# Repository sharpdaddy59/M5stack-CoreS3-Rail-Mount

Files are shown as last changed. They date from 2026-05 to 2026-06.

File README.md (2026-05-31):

# hydro-cores3-mount

Parametric OpenSCAD pipe-clamp + TS35 DIN-rail section for the
M5Stack CoreS3 on a vertical 1-1/2" Schedule-40 PVC pipe. Sibling
to [`hydro-tapco-mount`](../hydro-tapco-mount) — same pipe, same
clamp pattern, designed to share the rig with the camera mount.

The CoreS3 has a female TS35 clip on its back (35 mm × 7.5 mm
per IEC 60715). This part presents a printed male TS35 rail
section that the device clips onto. The rail runs **horizontally**
— perpendicular to the pipe, the standard DIN-rail orientation —
so gravity seats the device's spring-clip on the lower flange.
Slide the device on from either end of the rail. Reposition height
by loosening the clamp bolts and sliding the whole assembly up or
down the pipe.

The plain clamp half can optionally carry a **Seeed Grove DHT20**
temperature/humidity sensor on an extended bolt ear — see
[DHT20 sensor mount](#dht20-sensor-mount-optional) below.

## Files

| File | Re-render with | Notes |
|---|---|---|
| [`cores3-mount.scad`](cores3-mount.scad) | — | Source. Set `mode` at the top. |
| `cores3-mount_rail.stl` | `mode = "half_a"` (the rail half) | Print **one** |
| `cores3-mount_clamp.stl` | `mode = "half_b"` (the plain half) | Print **one** |
| `cores3-mount_clamp_DHT20.stl` | `mode = "half_b"` + `SENSOR_ENABLE = true` | Clamp half with the [DHT20 pad](#dht20-sensor-mount-optional). Print this **instead of** the plain clamp half. |

## BOM (per mount)

- 2 × M4 socket-cap bolts, 16 mm long (clamp bolts — one per side)
- 2 × M4 hex nuts (captive, one in each of Half A's bolt ears,
  hidden behind the rail once installed)
- A piece of 1-1/2" Schedule-40 PVC pipe (nominal OD 48.26 mm)
- An M5Stack CoreS3

**Optional — DHT20 sensor mount** (when `SENSOR_ENABLE = true`):

- 1 × Seeed Grove DHT20 temperature/humidity board
- 3 × M2 screws (length ≈ board thickness + pad thickness + nut)
- 3 × M2 hex nuts (captive in the pad's back-face pockets)

## Render

| Mode | Renders |
|---|---|
| `"half_a"` | Rail half — print one; rail-flange side down, supports around the screw-hole area. |
| `"half_b"` | Plain half — print one. |
| `"assembly"` | Both halves on a transparent dummy pipe. |
| `"exploded"` | Both halves separated with dummy bolts and nuts. |

Render (F6), export STL.

## Print orientation

**Half A (rail half):** prints **rail-flange side down** — the
flat rail face on the bed. The flange overhangs land directly on
the build plate, so they need no support, but the bolt-ear /
screw-hole area now overhangs the bed: **add supports around the
screw holes.**

**Half B (plain half):** prints with the bore axis vertical — it
stands as a half-tube on the bed, body and ears extruding as a
constant cross-section per layer, **no supports needed.**

## Print settings

- **Material:** PETG. Better fatigue tolerance for the
  captive-nut clamp force, and humidity-tolerant.
- **Layer height:** 0.2 mm.
- **Infill:** 20 % gyroid or grid.
- **Perimeters:** 3.
- **Supports:** around Half A's screw-hole area only; none for
  Half B.

## DHT20 sensor mount (optional)

Half B (the plain clamp half) can carry a **Seeed Grove DHT20**
temp/humidity board on a flat pad that extends one bolt ear. Turn
it on with `SENSOR_ENABLE = true` near the top of the SCAD; with it
`false` the clamp renders exactly as stock.

How it's laid out:

- The board bolts **flat** against the ear's outer (back) face and
  is mounted **vertically** — its long axis runs along the pipe so
  it stands up alongside the clamp rather than cantilevering far
  radially.
- Three **M2** through-holes match the Grove footprint: a pair on
  the connector edge `SENSOR_PAIR_DX` apart (20 mm), plus a single
  hole `SENSOR_PAIR_TO_SINGLE` away (30 mm). M2 nuts drop into
  **captive hex pockets on the pad's inner face**, so you only turn
  the screw.
- The holes sit **outboard of the ear tip** (`SENSOR_HOLE_INSET_X`)
  so the board clears the M4 clamp bolt — the bolt-head counterbore
  stays open through the pad, leaving hex-key access beside the
  board. **Tighten the clamp bolts before fitting the sensor.**
- The pad sits **flush with one clamp end** and the board overhangs
  the other; that flush edge is what keeps Half B printing
  **support-free**. Print with the flush end on the bed
  (`SENSOR_EXTEND_DIR = -1`, the default, needs no re-orientation;
  `+1` flips which end overhangs and wants a slicer flip).

The sensor dimensions are placeholders — **measure your board** and
adjust `SENSOR_PAIR_DX`, `SENSOR_PAIR_TO_SINGLE`, `SENSOR_HOLE_DIA`,
`SENSOR_NUT_FLATS`/`SENSOR_NUT_DEPTH`, and `SENSOR_HOLE_INSET_X`.
Built-in `assert`s catch a pad that's too thin for the nut or an
inner hole that creeps back over the bolt head. Keep the pad a plain
rectangle (no Y-varying fillets) or the no-support print breaks.

## Rail-clip clearance — why the plate is narrower than the rail

In a real DIN-rail install, the rail's flanges sit on a
backpanel and the device's clip hooks reach in past the flange
edges from outside the rail. To reproduce that here, the
printed support plate is exactly the width of the rail's HAT
TOP (27 mm) along the pipe axis — not the width of the flanges
(35 mm). The flanges overhang the plate by ~4 mm above and
below, leaving open air for the hooks to wrap around. If you
change `RAIL_HAT_W` or `PLATE_W` in the SCAD, keep them equal.

## Fit-test before final print

Run a fit-test of both halves at 0.3 mm layer / 0 % infill
/ 2 perimeters first. Wrap them around an actual offcut of the
pipe and dry-fit the CoreS3 onto the rail:

- **Device clip won't engage / binds going on** → increase
  `RAIL_GAP` (try 0.3 mm, then 0.4 mm).
- **Device wobbles or slides off when bumped** → reduce
  `RAIL_GAP` (try 0.1 mm).
- **Pipe still spins under modest hand torque** → reduce
  `PIPE_OD` by 0.3 mm.
- **Pipe-clamp halves bottom out before gripping** → increase
  `CLAMP_GAP`.
- **Captive nut spins in its hex pocket** → reduce `NUT_FLATS`
  by 0.1 mm.
- **DHT20 won't sit / screws miss the holes** → re-measure the
  board and correct `SENSOR_PAIR_DX` / `SENSOR_PAIR_TO_SINGLE`;
  for tight screws bump `SENSOR_HOLE_DIA`. **M2 nut spins** →
  reduce `SENSOR_NUT_FLATS` by 0.1 mm.

## Assembly

1. Drop one M4 hex nut into each of the two pockets on the
   outer faces of **Half A's** bolt ears (the rail side). They
   tuck behind the rail and stay captive.
2. Stand the pipe vertical. Hold Half A against one side of the
   pipe (with the rail facing the direction you want the device
   to point) and Half B against the opposite side so their bolt
   ears line up.
3. Drop an M4 bolt through each of **Half B's** counterbores
   (the back side, away from the device), across the gap, and
   into the captive nuts on Half A.
4. Tighten both bolts evenly with a hex key — alternate sides a
   few turns at a time so the halves close on the pipe square.
5. Slide the CoreS3 onto the rail from either end; gravity seats
   its clip on the lower flange.
6. **If using the DHT20 mount:** seat the three M2 nuts in the
   pad's back-face pockets, lay the board on the outer face, and
   drive the M2 screws from the board side. Do this *after* the
   clamp bolts are tight — the bolt head stays accessible beside
   the board, but it's easiest to reach with the sensor off.

## Re-aiming or relocating

- **Up / down the pipe:** loosen both clamp bolts 1–2 turns,
  slide the assembly up or down, retighten. The CoreS3 can stay
  clipped on the rail through this — or lift it off first.
- **Aim direction:** loosen, rotate the clamp around the pipe
  axis, retighten. The CoreS3 rotates with the clamp.
- **Remove the device:** slide it off either end of the rail.
- **Remove the clamp:** fully remove both bolts, separate the
  two halves, lift off the pipe.

## Pairing with the camera mount

Both `hydro-tapco-mount` and `hydro-cores3-mount` clamp to the
same 1.5" pipe, so they can sit on the same vertical run a few
inches apart. With both clamps rotated to the same direction,
the camera and the dashboard face the same way and you can see
both from one viewpoint.

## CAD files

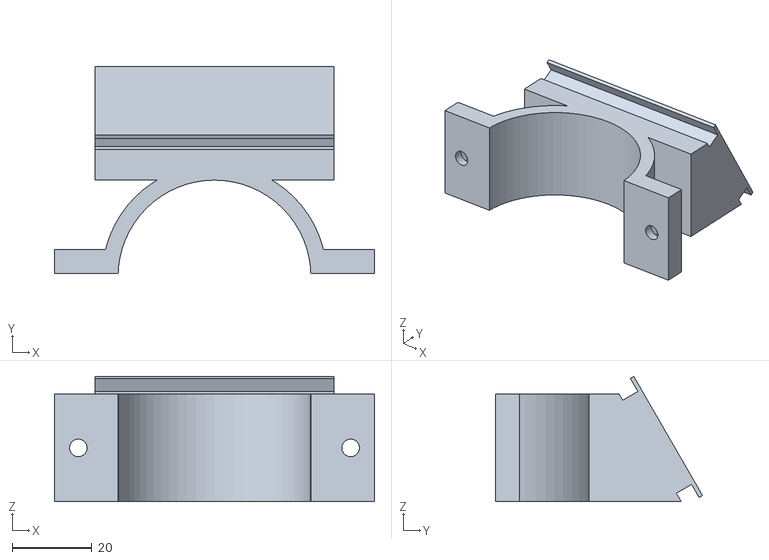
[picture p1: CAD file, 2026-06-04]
cores3-mount_rail_30.stl
80.5 x 52.1 x 31.5

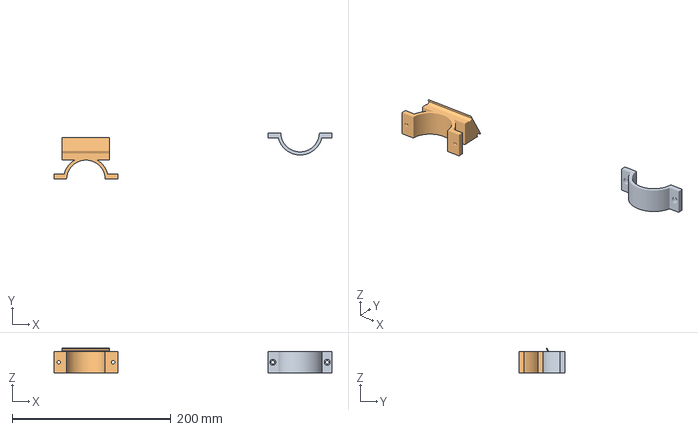
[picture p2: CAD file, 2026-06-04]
hydro-cores3-mount.3mf
350.4 x 57.4 x 31.5 mm
cores3-partb.stl
cores3-mount_rail_30.stl

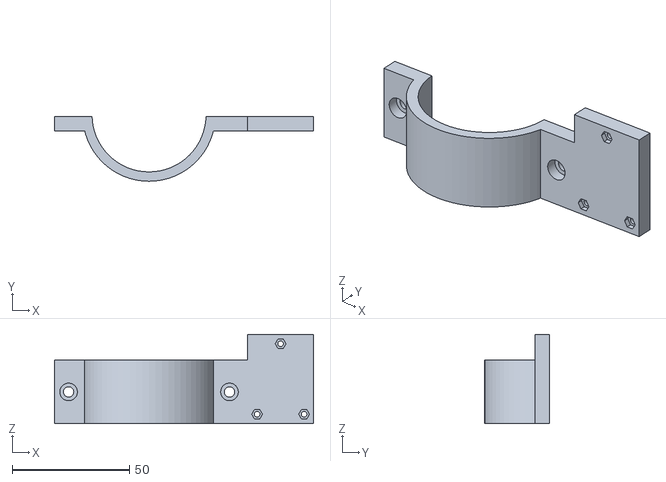
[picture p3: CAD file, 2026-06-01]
cores3-mount_clamp_DHT20.stl
110.2 x 27.5 x 38.0

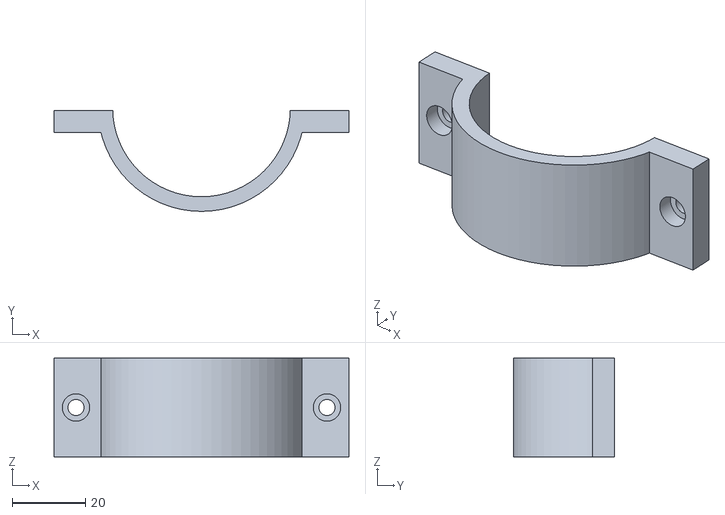
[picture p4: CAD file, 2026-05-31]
cores3-mount_clamp.stl
80.5 x 27.5 x 27.0

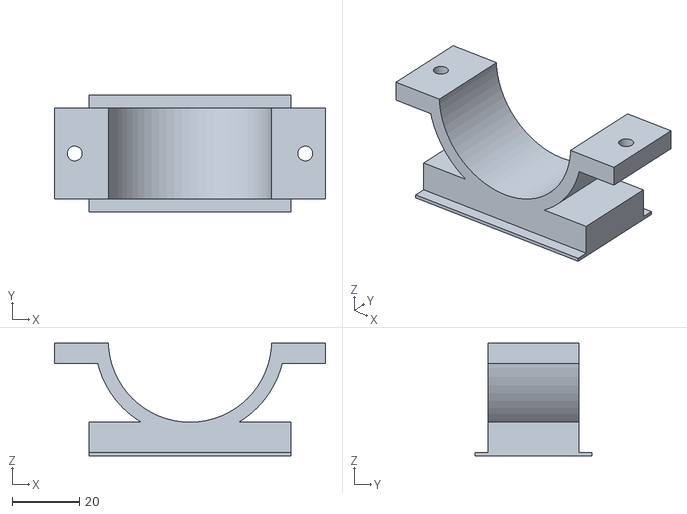
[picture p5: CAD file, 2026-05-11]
cores3-mount_rail.stl
80.5 x 34.6 x 33.5

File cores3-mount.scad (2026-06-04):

// cores3-mount.scad — parametric pipe clamp with TS35 DIN-rail
// section, for 1.5" Sch 40 PVC. Sibling of hydro-tapco-mount.
//
// Use case: the M5Stack CoreS3 has a female TS35 DIN-rail clip
// on its back (35 mm wide × 7.5 mm depth, IEC 60715). This part
// clamps to a vertical 1-1/2" PVC pipe and presents a printed
// male TS35 rail section that the device clips onto. Rail runs
// HORIZONTALLY (perpendicular to the pipe), so gravity seats the
// device's spring-clip onto the lower flange — the standard
// DIN-rail orientation. Slide the device on from either end of
// the rail. Loosen the clamp bolts to reposition up/down the pipe.
//
// Coordinate convention (design space):
//   Y = pipe axis (vertical in use).
//   Z = horizontal axis perpendicular to pipe, in the radial
//       direction the plate + rail extend. Plate face is at +Z.
//   X = the other horizontal axis. The rail length runs along X
//       (so device slides left/right). Bolts are along Z, with
//       the two bolt ears extending out in ±X.
//   Mating plane between the two halves: XY plane (Z = 0).
//   Half A (the half with the plate + rail): Z >= +G.
//   Half B (the half without): Z <= -G.
//
// Rail-clip clearance trick: in a real DIN-rail install, the
// rail's flanges sit on a backpanel and the device's clip hooks
// reach in past the flange edges from outside the rail. To
// reproduce that here, the printed support plate is exactly the
// width of the rail's HAT TOP (27 mm) along the pipe axis (Y),
// not the width of the flanges (35 mm). The flanges then overhang
// the plate by ~4 mm above and below in Y, leaving open air for
// the device's clip hooks to wrap around.
//
// Print orientation (recommended):
//   Half A (plate + rail): lay it RAIL-FLANGE SIDE DOWN — the flat
//   rail face on the bed. The flange overhangs then rest directly
//   on the build plate (no support needed there), but the bolt
//   ears / screw-hole area overhang the bed, so add supports
//   around the screw holes. (With RAIL_TILT != 0 the rail face is
//   tilted relative to the body; bedding that face flat just tips
//   the body — same approach, still no rail support needed.)
//   Half B (no rail): print with the bore axis VERTICAL — it sits
//   as a half-annulus tube on the bed; body and ears extrude as a
//   constant cross-section per layer, no supports needed.
//   The half_*_print() wrappers below just give a canonical export
//   placement; re-orient Half A in your slicer as above.
//
// Top-of-file `mode` selects what to render:
//   "half_a" / "half_b" / "assembly" / "exploded"

mode = "exploded";

// =============================================================
// PARAMETERS
// =============================================================

// ----- Pipe / clamp body -------------------------------------
PIPE_OD       = 48.5;   // 1.5" Sch 40 PVC nominal OD = 48.26 mm.
                        // CPVC and DWV pipe differ — measure first.
CLAMP_LEN     = 27.0;   // length of the clamp along the pipe axis.
                        // Matches the rail length so the rail sits
                        // on the body without cantilever along Y.
CLAMP_GAP     = 1.5;    // mating-plane gap when un-tightened.
                        // Bolts close this gap to grip. If halves
                        // bottom out before grip, increase.
WALL          = 4.0;    // shell wall thickness

// ----- Fasteners (M4 socket cap + hex nut, BOTH sides) -------
// Bolt heads recess into Half B (the no-rail half) so a hex key
// can reach them from the back of the assembly. Captive nuts
// drop into pockets on Half A — once installed they sit tucked
// behind the rail and never need to be touched again.
BOLT_DIA      = 4.4;    // through-hole, M4 clearance fit
HEAD_DIA      = 7.5;    // socket-cap head counterbore
HEAD_DEPTH    = 4.0;
NUT_FLATS     = 7.2;    // M4 hex nut across-flats
NUT_DEPTH     = 3.5;
EAR_LEN       = 12.0;   // bolt-ear extension past the shell
EAR_THK       = 6.0;    // bolt-ear thickness (perpendicular to
                        // mating plane)

// ----- DHT20 sensor mounting pad (Half B only) ---------------
// Extends ONE bolt ear into a flat pad. The Grove DHT20 breakout
// bolts down FLAT against the pad's INNER (+Z) face, mounted
// VERTICAL: its long axis runs along Y (the pipe axis) so it stands
// up alongside the pipe instead of cantilevering radially.
//
// 3 mounting holes (Seeed Grove DHT20): a PAIR on the Grove-
// connector edge, SENSOR_PAIR_DX apart along X, and a SINGLE hole
// SENSOR_PAIR_TO_SINGLE away along Y.
//
// The holes sit OUTBOARD of Half A's bolt-ear tip (EAR_OUTER_X),
// so the +Z face there is open air -- the board can mount on it
// without fouling Half A on assembly. Mounting on +Z keeps the M4
// clamp-bolt heads and their hex key alone on the OUTER (-Z) back
// face, completely clear of the board (and the clamp can still be
// loosened/repositioned with the CoreS3 clipped on). The M4
// bolt-head counterbore still passes through the pad's inner weld
// strip, opening only on the back. Because the board (~40 mm) is
// longer than the clamp, the pad hangs past ONE clamp end (the
// board's natural overhang) and sits FLUSH with the OTHER. That
// flush edge is what lets Half B print support-free: the pad's
// outboard strip is carried straight up from the bed. A centred
// pad would overhang both ends and need supports.
//
// M2 screws from the board (+Z) side; M2 nuts are CAPTIVE in hex
// pockets on the pad's OUTER (-Z) back face (same idea as Half A's
// nut_pocket) so you only turn the screw.
//   >>> SENSOR_* dims are "MEASURE YOUR BOARD" values <<<
//   >>> Keep the pad a plain rectangle (Y-constant, no fillets)
//       or the no-support vertical print of Half B breaks. <<<
SENSOR_ENABLE   = true;   // master on/off
SENSOR_EAR_SIDE = +1;     // which ear: +1 (+X) or -1 (-X)

// Hole pattern (measured off the board)
SENSOR_PAIR_DX        = 20.0; // pair spacing along X  (connector edge)
SENSOR_PAIR_TO_SINGLE = 30.0; // pair -> single hole, along Y
SENSOR_SINGLE_DX      = 0.0;  // single-hole X offset from pair centre
                              // (0 = centred between the pair)
SENSOR_HOLE_INSET_X   = 46.0; // X of the INNER pair hole. Bounded by
                              // Half A's bolt-ear TIP (EAR_OUTER_X ~= 40):
                              // the board mounts on the pad's INNER (+Z)
                              // face, so its holes must sit OUTBOARD of the
                              // ear or the PCB would foul Half A on assembly.
                              // Lower = tucked in tighter (min ~EAR_OUTER_X+4);
                              // raise it if your measured PCB edge overhangs
                              // inboard past the ear tip.
SENSOR_HOLE_DIA       = 2.4;  // M2 clearance, through the pad

// Print alignment: the board hangs past one clamp end; the pad is
// flush with the OTHER end so it prints support-free.
SENSOR_EXTEND_DIR = -1;   // which end the board hangs past:
                          //  -1 = past the Y=0 end (pad flush at
                          //       Y=CLAMP_LEN, the default print-bed
                          //       face -> no part change needed)
                          //  +1 = past the Y=CLAMP_LEN end (flip the
                          //       part in the slicer to print)

// Pad
SENSOR_PAD_THK    = EAR_THK;  // thickness (Z); holds the captive nut,
                          // keep <= EAR_THK and > nut depth + ~1
SENSOR_PAD_MARGIN = 4.0;  // border around each hole. >= the captive
                          // nut-pocket radius (NUT_FLATS/cos(30)/2) plus
                          // ~1.5 mm wall, or the pocket breaches the edge.

// Captive M2 hex-nut pockets on the pad's OUTER (-Z) back face
SENSOR_NUT_POCKET = true;
SENSOR_NUT_FLATS  = 4.0;   // M2 nut across-flats (MEASURE)
SENSOR_NUT_DEPTH  = 1.8;   // M2 nut thickness  (MEASURE)

// ----- Lead-clearance relief on the board (+Z) face ----------
// The Grove connector + AHT20 solder tails poke ~1 mm proud of the
// PCB back. Recess the board-contact face so the board seats on three
// bosses at the screw holes (a standoff plate) and the tails hang in
// clear air -- so tightening the M2 screws can't bend/crack the PCB.
// Prints fine: the recess only removes the +Z surface; the solid -Z
// half of the pad still backs every layer.
SENSOR_RELIEF        = true;
SENSOR_RELIEF_DEPTH  = 2.0;  // recess depth; > the ~1 mm lead protrusion
SENSOR_RELIEF_INSET  = 2.0;  // recess inset from the board-rect edges
SENSOR_BOSS_DIA      = 7.0;  // seating-boss diameter at each screw. Keep it
                             // wider than 2*(SENSOR_PAD_MARGIN-INSET) so the
                             // boss crosses the recess wall into the rim
                             // (a tangent boss would be non-manifold).
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

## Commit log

2026-05-11 feat: initial commit — parametric CoreS3 pipe-clamp + TS35 rail mount
    OpenSCAD source, exported STLs, 3MF, and README.
    [cores3-mount.scad, cores3-mount_clamp.stl, cores3-mount_rail.stl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]
2026-05-11 chore: re-orient Half A for print (rail-flange down) + update README
    Half A now prints rail-flange-side down with supports around the
    screw-hole area; re-exported STL and 3MF, README print sections
    updated to match.
    [cores3-mount_rail.stl, hydro-cores3-mount.3mf]
2026-05-11 docs: update SCAD print-orientation comment to match (Half A rail-flange down)
    [cores3-mount.scad]
2026-05-31 feat: add parametric DHT20 sensor mounting pad to clamp half (Half B)
    Extends one bolt ear into a flat pad for a Seeed Grove DHT20 board,
    mounted vertically (long axis along the pipe). Three M2 through-holes
    (20 mm pair + single 30 mm away) with captive hex-nut pockets on the
    inner face. Holes sit outboard of the ear tip so the board clears the
    M4 clamp bolt, and the pad is flush with one clamp end so Half B still
    prints support-free bore-axis-vertical. Gated behind SENSOR_ENABLE;
    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
    [cores3-mount.scad, cores3-mount_clamp.stl]
2026-05-31 docs: document DHT20 mount; ship plain + DHT20 clamp STLs
    Add a DHT20 sensor-mount section, BOM, fit-test and assembly notes
    to the README, and list the new variant in the Files table.
    Split the clamp into two STLs: cores3-mount_clamp.stl is the stock
    plain half (SENSOR_ENABLE=false, the default) and
    cores3-mount_clamp_DHT20.stl is the half with the DHT20 pad
    (SENSOR_ENABLE=true). Print one or the other.
    [cores3-mount.scad, cores3-mount_clamp.stl, cores3-mount_clamp_DHT20.stl]
2026-06-01 feat: rework DHT20 mount — back-face board, trimmed pad, lead relief
    Mount the Grove DHT20 on the pad's inner (+Z) face so the M4 clamp-bolt
    heads and hex key own the outer (-Z) back face, clear of the board (and
    the clamp can still be repositioned with the CoreS3 clipped on). Captive
    M2 nuts move to the back face to match.
    Trim the pad to a board-hugging rectangle plus a neck back to the bolt
    ear, deleting the dead corner the old full slab carried past the clamp
    end next to the M4 bolt. Restore hole margin to 4 mm so the captive nut
    pockets keep a wall.
    Add a standoff relief on the board face: a 2 mm pocket with raised bosses
    at the three screw holes, so the PCB seats only on the bosses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
    [cores3-mount.scad, cores3-mount_clamp_DHT20.stl]
2026-06-04 feat: add parametric rail down-tilt + radial standoff for camera aim
    Pitch the rail about its length axis (X) so the clipped CoreS3 aims its
    camera downward. RAIL_TILT (deg) sets the angle; the rail and its
    backing plate pitch as ONE rigid unit so the clip still meets the
    identical rail-on-plate geometry (flanges proud, overhang into open air,
    open front) and still slides on from the rail ends. A hat-width gusset,
    kept entirely below the plate, welds it back to the body without ever
    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
    [cores3-mount.scad, cores3-mount_rail_30.stl, hydro-cores3-mount.3mf]
